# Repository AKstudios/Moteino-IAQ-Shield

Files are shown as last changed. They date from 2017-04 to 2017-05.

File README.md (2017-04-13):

# Moteino IAQ Shield

This is an indoor air quality shield for Motenio that measures temperature, humidity, light intensity, PM2.5, CO2 and VOC concentrations. Power through micro USB.
<br><br>
Sensors used:<br>
SHT31/35<br>
TSL2591<br>
CCS811<br>
PMS5003/7003 (molex connector for external module)<br>

<p align="center">
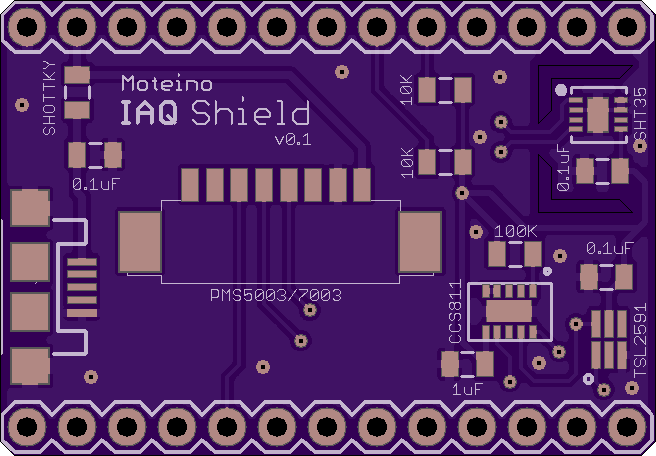
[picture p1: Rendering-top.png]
CRT Sensor Board
  
</p>

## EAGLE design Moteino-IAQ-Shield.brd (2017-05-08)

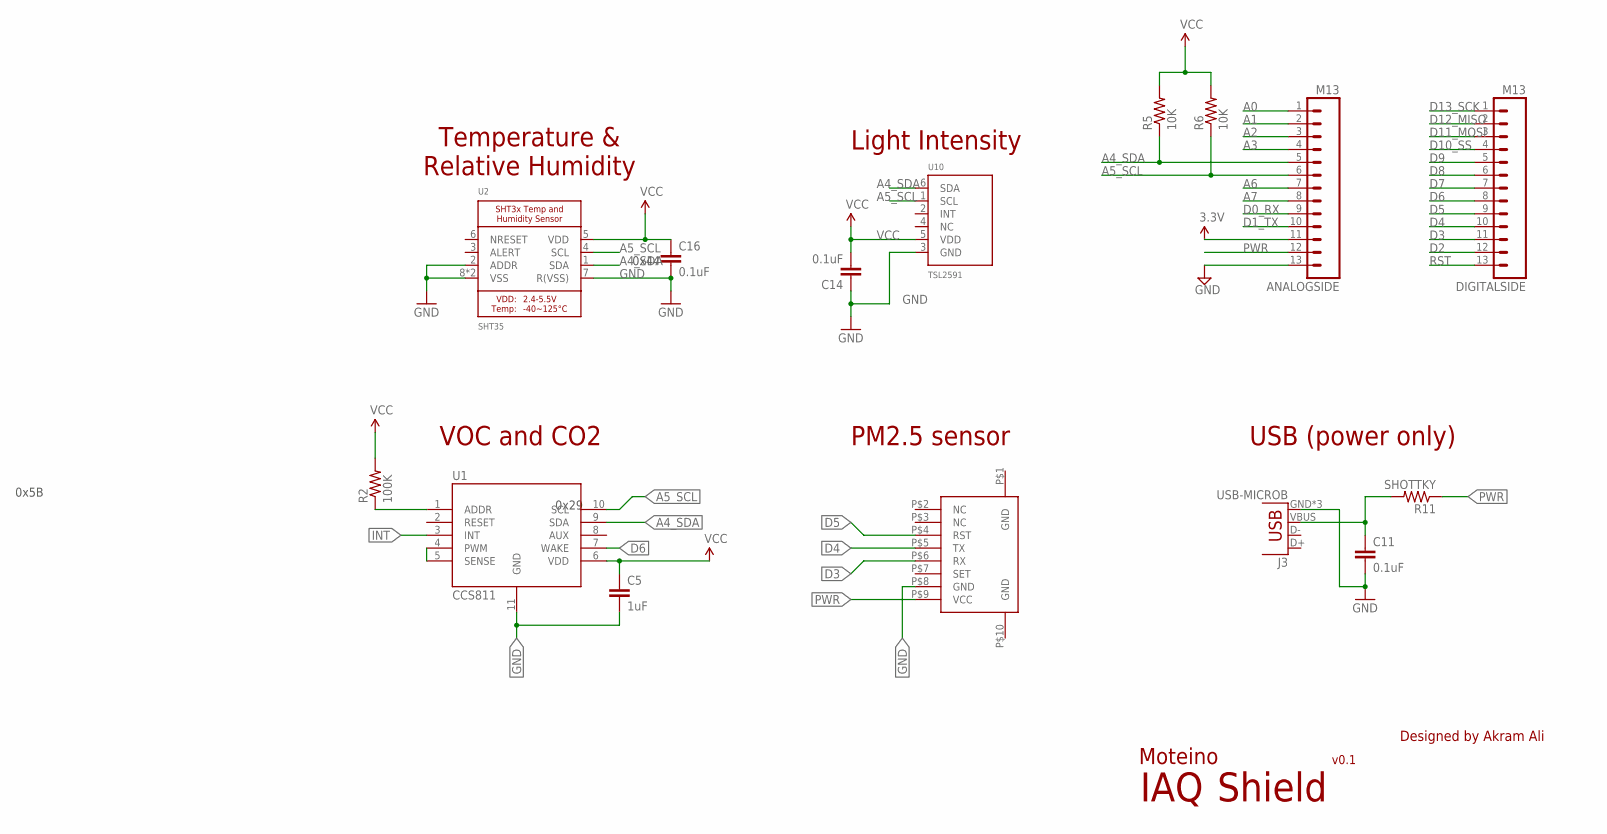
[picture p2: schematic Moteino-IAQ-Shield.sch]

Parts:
ANALOGSIDE: M13; 1X13
C5: 1uF; 0805; MPN CC0805KKX7R7BB105
C11, C14, C16: 0.1uF; 0805; MPN CC0805KRX7R9BB104
DIGITALSIDE: M13; 1X13
J3: USB-MICROB; MPN 47346-0001
R2: 100K; 0805; MPN 311-100KCRCT-ND
R5, R6: 10K; 0805; MPN RC0805FR-0710KL
R11: SHOTTKY; 0805; MPN SD0805S040S0R5
U1: CCS811; LGA; MPN CCS811
U2: SHT35; SHT3X; MPN SHT35-DIS-B
U10: TSL2591; DFN6_TAOS; MPN TSL25911FN
U$1: PMS5003/7003; 0532610871

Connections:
A0: ANALOGSIDE.1
A1: ANALOGSIDE.2
A2: ANALOGSIDE.3
A3: ANALOGSIDE.4
A4_SDA: ANALOGSIDE.5, R5.1, U1.9 (SDA), U2.1 (SDA), U10.6 (SDA)
A5_SCL: ANALOGSIDE.6, R6.1, U1.10 (SCL), U2.4 (SCL), U10.1 (SCL)
A6: ANALOGSIDE.7
A7: ANALOGSIDE.8
D0_RX: ANALOGSIDE.9
D1_TX: ANALOGSIDE.10
D2: DIGITALSIDE.12
D3: DIGITALSIDE.11, U$1.P$6 (RX)
D4: DIGITALSIDE.10, U$1.P$5 (TX)
D5: DIGITALSIDE.9, U$1.P$4 (RST)
D6: DIGITALSIDE.8, U1.7 (WAKE)
D7: DIGITALSIDE.7
D8: DIGITALSIDE.6
D9: DIGITALSIDE.5
D10_SS: DIGITALSIDE.4
D11_MOSI: DIGITALSIDE.3
D12_MISO: DIGITALSIDE.2
D13_SCK: DIGITALSIDE.1
GND: ANALOGSIDE.13, C5.2, C11.2, C14.1, C16.2, J3.GND, J3.MT1 (GND), J3.MT2 (GND), U1.11 (GND), U2.2 (ADDR), U2.7 (R(VSS)), U2.8 (VSS), U2.THERMAL (VSS), U10.3 (GND), U$1.P$8 (GND)
INT: U1.3 (INT)
unnamed: R2.1, U1.1 (ADDR)
unnamed: U1.4 (PWM), U1.5 (SENSE)
PWR: ANALOGSIDE.12, R11.1, U$1.P$9 (VCC)
RST: DIGITALSIDE.13
VBUS: C11.1, J3.VBUS, R11.2
VCC: ANALOGSIDE.11, C5.1, C14.2, C16.1, R2.2, R5.2, R6.2, U1.6 (VDD), U2.5 (VDD), U10.5 (VDD)

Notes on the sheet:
Moteino
Designed by Akram Ali
IAQ
Temperature & Relative Humidity
0x44
Light Intensity
0x29
PM2.5 sensor
USB (power only)
Shield
v0.1
VOC and CO2
0x5B

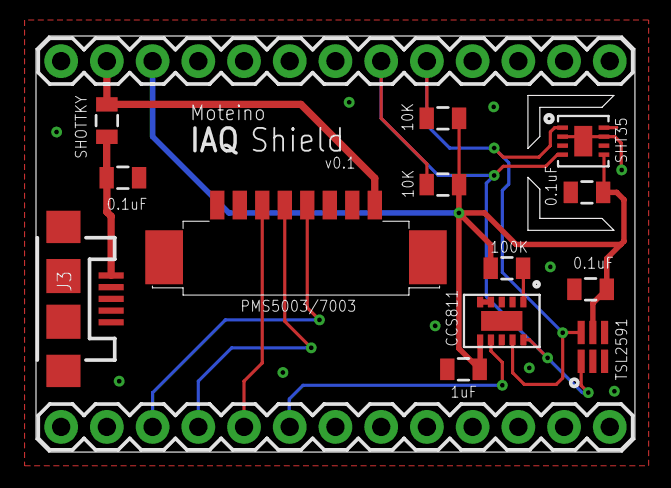
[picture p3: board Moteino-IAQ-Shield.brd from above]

Board: 2 copper layers, 33.3 x 23.1 mm, 15 parts (0 on the bottom side), 12 nets.

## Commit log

2017-04-12 Added EAGLE files
    [Moteino-IAQ-Shield.brd, Moteino-IAQ-Shield.sch]
2017-04-13 Trace and component adjustments
    [Moteino-IAQ-Shield.brd, Moteino-IAQ-Shield.sch]
2017-04-17 Updated library for Molex connector
    [Moteino-IAQ-Shield.brd, Moteino-IAQ-Shield.sch]
2017-05-08 Connected GND trace for SHT sensor
    [Moteino-IAQ-Shield.brd, Moteino-IAQ-Shield.sch]

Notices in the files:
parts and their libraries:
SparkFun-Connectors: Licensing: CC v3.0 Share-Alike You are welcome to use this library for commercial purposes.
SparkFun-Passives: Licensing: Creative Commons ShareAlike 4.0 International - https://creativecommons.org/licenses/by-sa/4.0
